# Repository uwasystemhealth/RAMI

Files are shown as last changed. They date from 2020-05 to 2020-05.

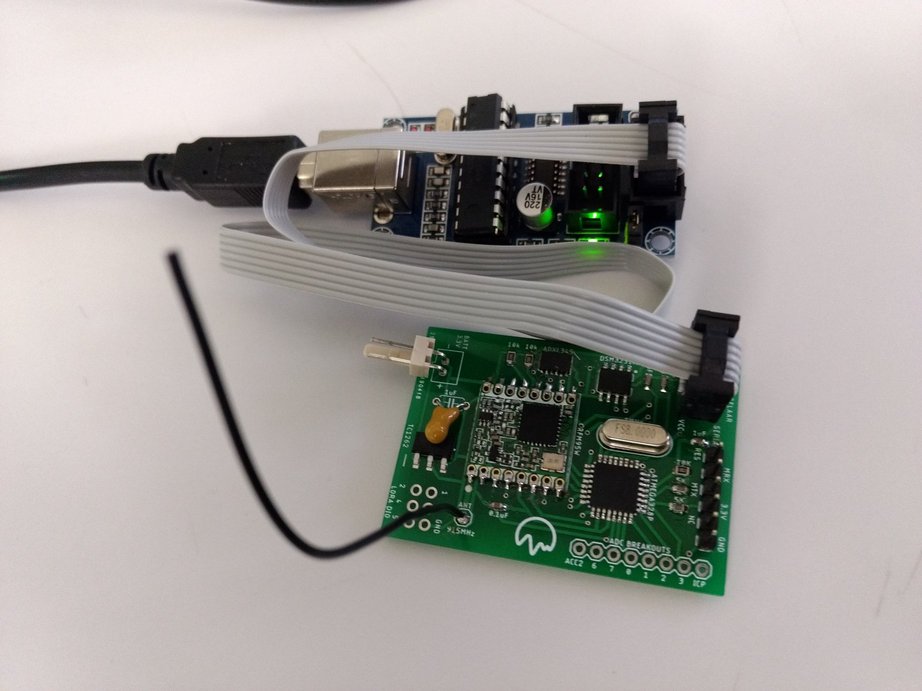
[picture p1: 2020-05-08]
figures/USBtinyISP.jpg

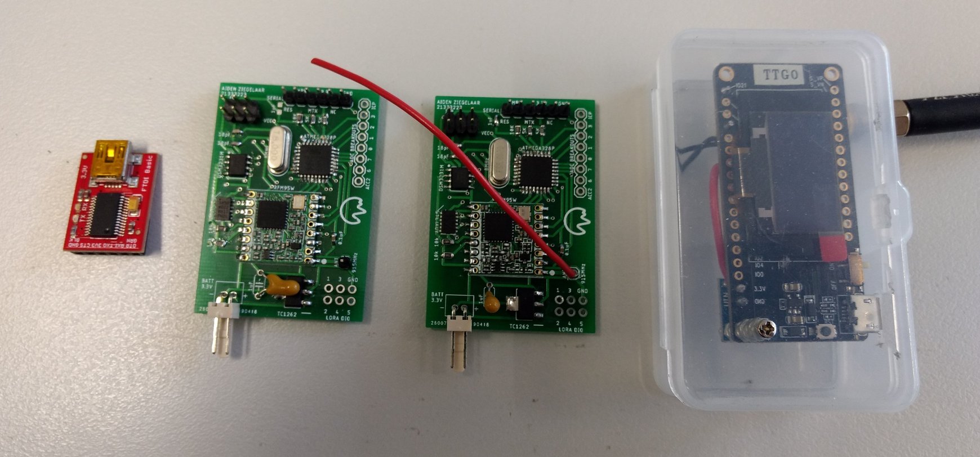
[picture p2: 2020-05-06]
figures/IMG_20200214_084231396.jpg

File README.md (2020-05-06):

# Remote Asset Management Indicator (RAMI)

This is a companion repository to the paper
_Sensing system for low cost condition monitoring of remote assets_
by Aiden J Ziegelaar, Ben C Travaglione & Melinda R Hodkiewicz,
published in
[4th IFAC Workshop on Advanced Maintenance Engineering, Services and Technologies](https://www.amest2020.eng.cam.ac.uk/).

This repository contains all the information necessary to replicate the results presented in the paper.

The majority of the notes are contained within the [Jupyter](https://jupyter.org/) notebook [RAMI.ipynb](RAMI.ipynb).

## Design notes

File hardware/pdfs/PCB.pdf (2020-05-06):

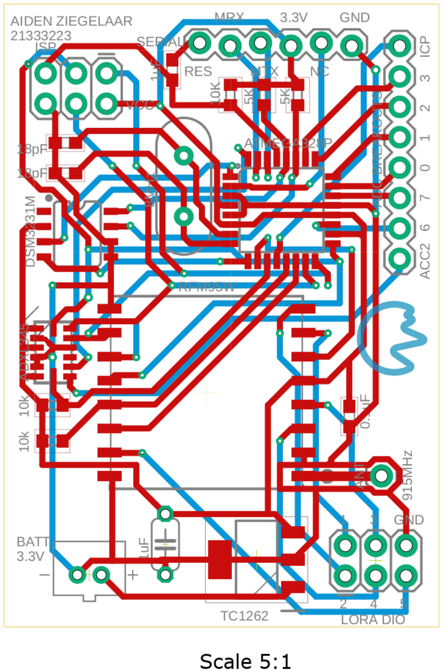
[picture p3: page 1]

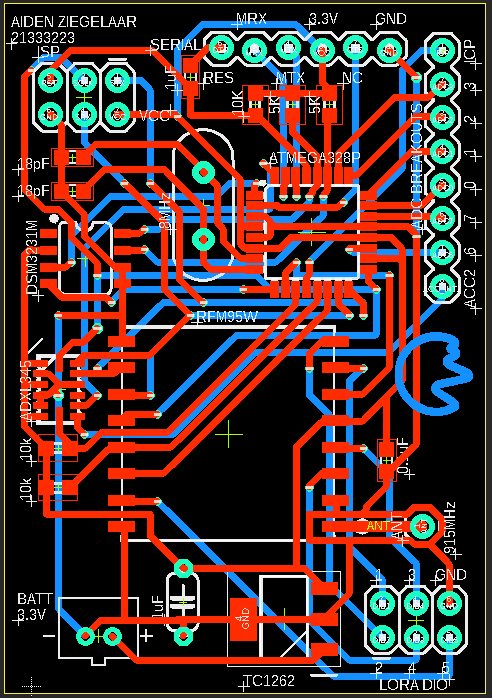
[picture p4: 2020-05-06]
figures/board_layout.png

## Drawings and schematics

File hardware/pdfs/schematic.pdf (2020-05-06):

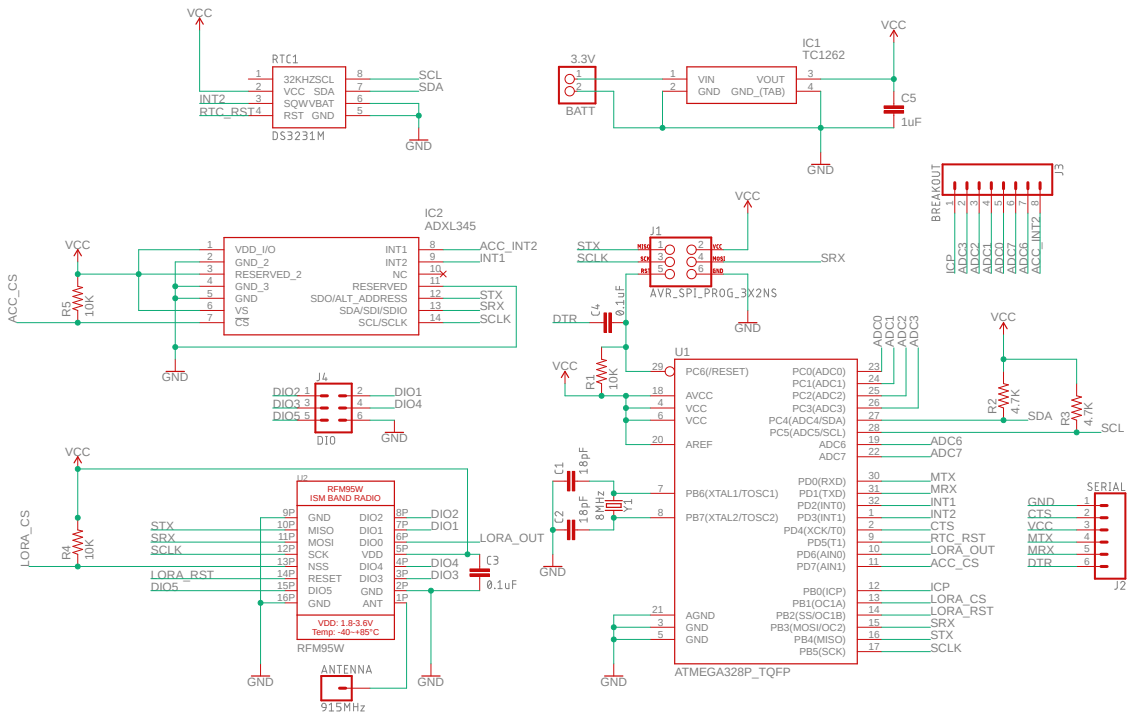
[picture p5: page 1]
ATMEGA328P_TQFP; ADXL345; VCC; GND; 1uF 10K ¹⁰K; PB5(SCK); PB7(XTAL2/TOSC2) 8; PB6(XTAL1/TOSC1) 7; GND 3 GND 5; VCC 4 VCC 6; AGND 21; AREF 20; AVCC 18; PB4(MISO); 16 PB3(MOSI/OC2); 13 PB0(ICP); PD7(AIN1); 11 PD6(AIN0); PD4(XCK/T0); PD3(INT1); PD2(INT0); 32 PD1(TXD); 31 PD0(RXD); ADC7; 22 ADC6; 19 PC5(ADC5/SCL); 28 PC4(ADC4/SDA); 27 PC3(ADC3); 26 PC2(ADC2); 25 PC1(ADC1); 24 PC0(ADC0); 23 PC6(/RESET) 29 U1; GND 5; GND_2 2; GND_3 4; INT1; INT2; RESERVED; 11 RESERVED_2 3; SCL/SCLK; 14 SDA/SDI/SDIO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

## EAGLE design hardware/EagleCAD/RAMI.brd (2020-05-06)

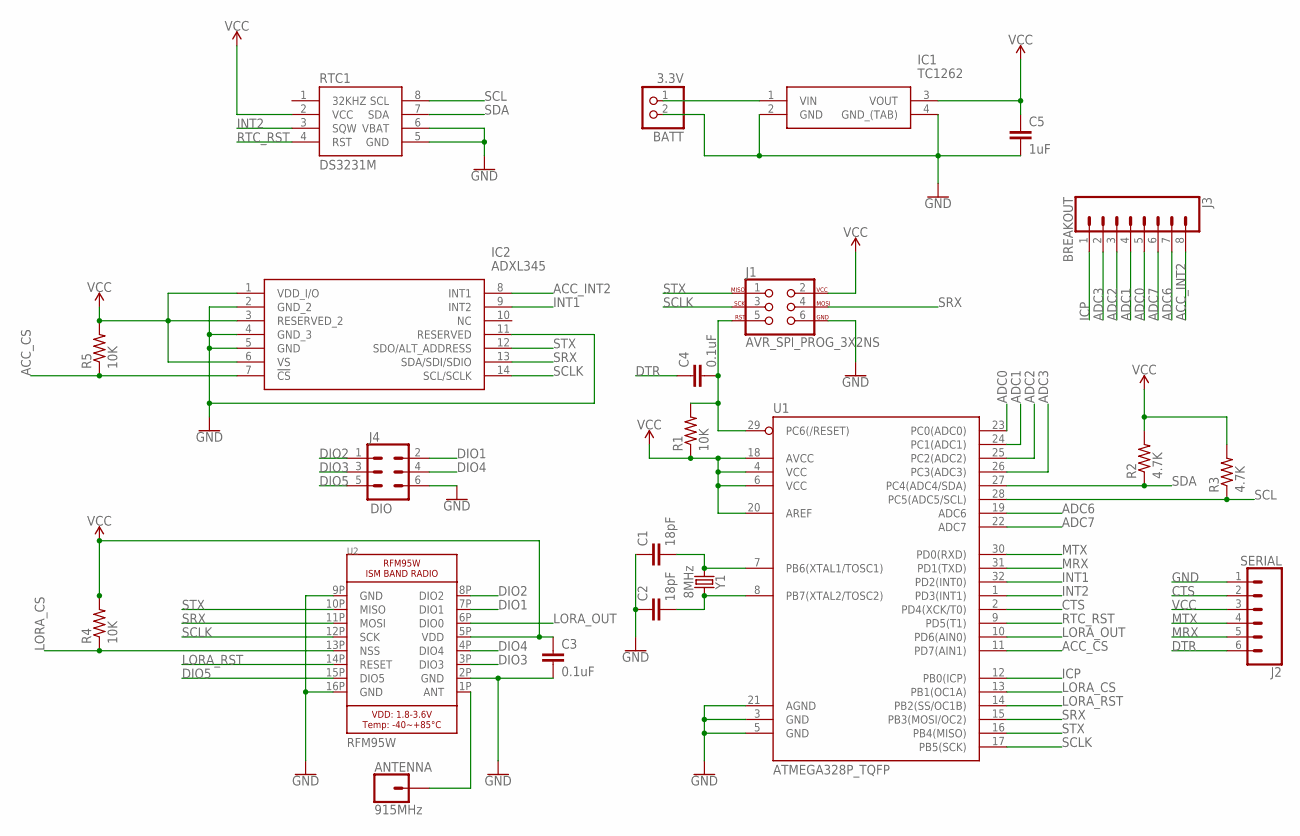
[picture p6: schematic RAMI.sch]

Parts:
ANTENNA: 915MHz; 1X01
BATT: 3.3V; JST-PH-2-THM
C1, C2: 18pF; 0603
C3, C4: 0.1uF; 0603
C5: 1uF; C050-024X044
IC1: TC1262; SOT230P700X180-4N
IC2: ADXL345; LGA14R80P3X6_300X500X100
J1: AVR_SPI_PROG_3X2NS; 2X3-NS
J2: SERIAL; 1X06_LOCK
J3: BREAKOUT; 1X08
J4: DIO; 2X3-NS
R1, R4, R5: 10K; R0603
R2, R3: 4.7K; R0603
RTC1: DS3231M; SO08
U1: ATMEGA328P_TQFP; TQFP32-08
U2: RFM95W; RFM95W_SMT
Y1: 8MHz; HC49US

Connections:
ACC_CS: IC2.7 (!CS), R5.1, U1.11 (PD7(AIN1))
ACC_INT2: IC2.8 (INT1), J3.8
ADC0: J3.5, U1.23 (PC0(ADC0))
ADC1: J3.4, U1.24 (PC1(ADC1))
ADC2: J3.3, U1.25 (PC2(ADC2))
ADC3: J3.2, U1.26 (PC3(ADC3))
ADC6: J3.7, U1.19 (ADC6)
ADC7: J3.6, U1.22 (ADC7)
ANT: ANTENNA.1, U2.1P (ANT)
CTS: J2.2, U1.2 (PD4(XCK/T0))
DIO1: J4.2, U2.7P (DIO1)
DIO2: J4.1, U2.8P (DIO2)
DIO3: J4.3, U2.3P (DIO3)
DIO4: J4.4, U2.4P (DIO4)
DIO5: J4.5, U2.15P (DIO5)
DTR: C4.1, J2.6
GND: BATT.2 (1), C1.1, C2.1, C3.2, C5.2, IC1.2 (GND), IC1.4 (GND_(TAB)), IC2.2 (GND_2), IC2.4 (GND_3), IC2.5 (GND), IC2.11 (RESERVED), J1.6, J2.1, J4.6, RTC1.5 (GND), RTC1.6 (VBAT), U1.3 (GND), U1.5 (GND), U1.21 (AGND), U2.2P (GND), U2.9P (GND), U2.16P (GND)
ICP: J3.1, U1.12 (PB0(ICP))
INT1: IC2.9 (INT2), U1.32 (PD2(INT0))
INT2: RTC1.3 (SQW), U1.1 (PD3(INT1))
LORA_CS: R4.1, U1.13 (PB1(OC1A)), U2.13P (NSS)
LORA_OUT: U1.10 (PD6(AIN0)), U2.6P (DIO0)
LORA_RST: U1.14 (PB2(SS/OC1B)), U2.14P (RESET)
MRX: J2.5, U1.31 (PD1(TXD))
MTX: J2.4, U1.30 (PD0(RXD))
unnamed: C1.2, U1.7 (PB6(XTAL1/TOSC1)), Y1.1
unnamed: C2.2, U1.8 (PB7(XTAL2/TOSC2)), Y1.2
unnamed: BATT.1 (2), IC1.1 (VIN)
RST: C4.2, J1.5, R1.2, U1.29 (PC6(/RESET))
RTC_RST: RTC1.4 (RST), U1.9 (PD5(T1))
SCL: R3.1, RTC1.8 (SCL), U1.28 (PC5(ADC5/SCL))
SCLK: IC2.14 (SCL/SCLK), J1.3, U1.17 (PB5(SCK)), U2.12P (SCK)
SDA: R2.1, RTC1.7 (SDA), U1.27 (PC4(ADC4/SDA))
SRX: IC2.13 (SDA/SDI/SDIO), J1.4, U1.15 (PB3(MOSI/OC2)), U2.11P (MOSI)
STX: IC2.12 (SDO/ALT_ADDRESS), J1.1, U1.16 (PB4(MISO)), U2.10P (MISO)
VCC: C3.1, C5.1, IC1.3 (VOUT), IC2.1 (VDD_I/O), IC2.3 (RESERVED_2), IC2.6 (VS), J1.2, J2.3, R1.1, R2.2, R3.2, R4.2, R5.2, RTC1.2 (VCC), U1.4 (VCC), U1.6 (VCC), U1.18 (AVCC), U1.20 (AREF), U2.5P (VDD)

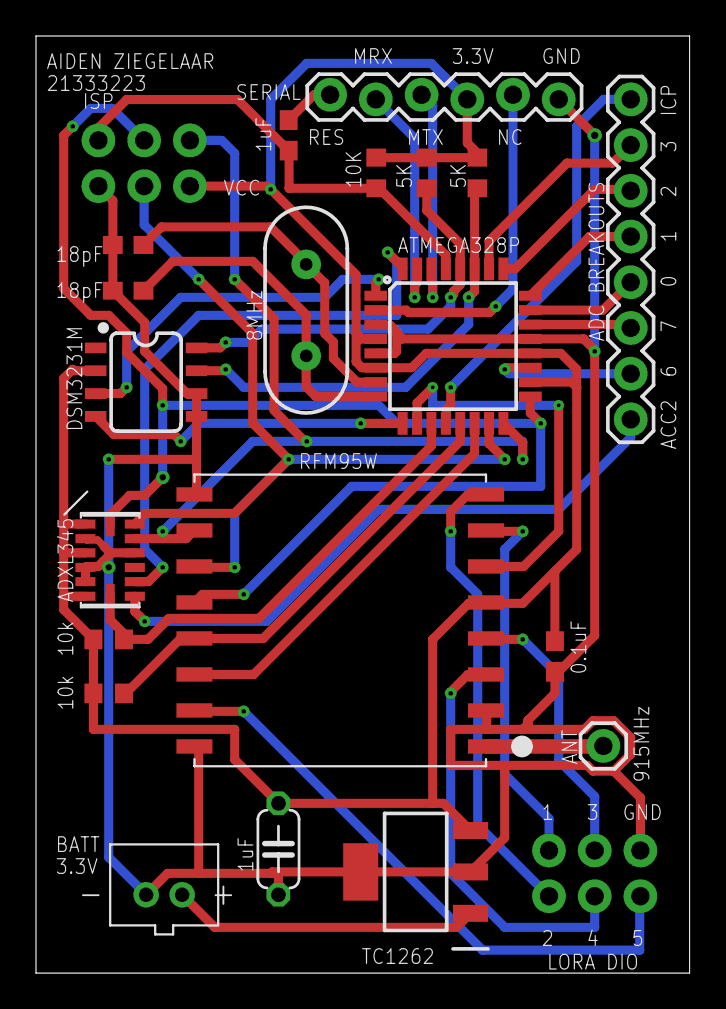
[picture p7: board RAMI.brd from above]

Board: 2 copper layers, 36.3 x 52.1 mm, 22 parts (0 on the bottom side), 36 nets.

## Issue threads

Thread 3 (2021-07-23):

RAMI Enclosure

Mechsmith, 2021-07-23:
Consists of:
- Decide on final design
- Draw design in Autodesk Inventor
- 3D print prototype
- Iterate to meet IP rating (>IP65 ideal)

Mechsmith, 2021-11-26:
The decision was made to go ahead and create the RAMI enclosure for the existing RAMI board. Once the RAMI v2 is complete, a separate enclosure can be made for that too.

Current enclosure has the body complete, but gasket channel still needs work. Lid and screw holes still need to be created.

Mechsmith, 2022-01-27:
Gasket channel is complete, but needs sizing to be matched to an off-the-shelf O-ring. Lid and screw holes still need to be completed (equivalent gasket channel needs to be sized on the lid too).

mhodki, 2022-06-03:
Update by Teams from Patrick today
Update on the RAMI is that I have found an o-ring supplier in Kwinana, but it is unclear exactly what sizes they have, so I'm going to need to drive down and have a look. I did an IP test using some DIY gasket, but faced a problem with the print de-laminating when I screwed the lid on. Next steps are to go to Kwinana to have a look and print out the new version of the enclosure with modified screw holes (drawing is already made).

Mechsmith, 2022-06-30:
Attempted to modify closure design to accommodate the O-ring, however printing it in ABS keeps failing so we need to order more PLA to complete the print (the O-ring groove should be the correct size in the updated CAD drawing).

mhodki, 2022-07-15:
@Mechsmith  - remind me again if you will be using RAMI for your thesis.

Mechsmith, 2022-07-21:
@mhodki Yes, if we can get some RAMIs operational they will be a good test case in my thesis.

mhodki, 2022-10-21:
Closing this project and now being worked on as part of Patrick's thesis

Closed 2022-10-21.

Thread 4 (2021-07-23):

LoRa IDs for Adrian

Mechsmith, 2021-07-23:
Consists of:
- Are LoRa IDs manually configurable?
- Produce a list of LoRa IDs for the PCBs we currently have
- Give the IDs to Adrian for the SimplyCity IoT network

Mechsmith, 2021-09-03:
Adrian has responded saying that he will look into setting up a trial with SimplyCity IoT.

Mechsmith, 2021-10-15:
[RE_ RAMI questions.pdf](https://github.com/uwasystemhealth/RAMI/files/7350542/RE_.RAMI.questions.pdf)

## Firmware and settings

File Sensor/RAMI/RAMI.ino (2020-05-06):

#include <avr/sleep.h>
#include <avr/power.h>
#include <Wire.h>
#include <SPI.h>
#include <SparkFun_ADXL345.h>
#include <RtcDS3231.h>
#include <EEPROM.h>
#include <LoRa.h>

//#define DEBUG // Comment out this line to turn off debug mode and save some power

#ifdef DEBUG
#define DEBUG_PRINT(msg) Serial.println(msg)
#else
#define DEBUG_PRINT(msg)
#endif

#define BAND            915E6  // Different RAMI devices have different bands
#define DEVICE_ID       0x01
#define TIMEOUT         200 //time to wait for a response from the server (x50ms)


// ADXL345 definitions
#define accIntPin             2
#define accCsPin              7
#define accRange              8 // valid values are 2g, 4g, 8g or 16g, (2, 4, 8, 16)
#define accThreshold          20 // The Scale Factor is 62.5mg/LSB, values are between 0 and 255.

//LoRa definitions
#define loraIntPin            6
#define loraRstPin            10
#define loraCsPin             9

//RTC Definitions
#define rtcIntPin             3
#define rtcRstPin             5
#define monitoringTime        5 // Time period to collect ADXL samples (seconds)
#define rtcActiveAlarmTime    120 // Time between wakes on active state (seconds)
                               // it is important that this time is greater than
                               // the monitoring time
#define rtcInactiveAlarmTime  240 // must be <86400 (one day) // Time between hearbeats (seconds)

// lets interrupts safely modify
volatile bool rtcInterruptFlag = false;
volatile bool accInterruptFlag = false;
volatile bool accInactiveInterruptFlag = false;
volatile bool stateFlag = false;

unsigned long nonce = 0;

unsigned int previous_magnitude = 0;

ADXL345 adxl;

RtcDS3231<TwoWire> Rtc(Wire);

void setup() {
  //////////////// Configure ATMEGA328P ////////////////
  SPI.begin();
  // turn off all non essential components
  power_adc_disable   ();
  #ifndef DEBUG
  power_timer1_disable();
  power_usart0_disable(); // This disables serial communications
  #else
  Serial.begin(9600);
  DEBUG_PRINT("DEBUG enabled");
  #endif

  ////////////////// Configure LoRa ////////////////
  LoRa.setPins(loraCsPin, loraRstPin, loraIntPin);
  LoRa.setSpreadingFactor(12);
  LoRa.setSignalBandwidth(31.25E3);
  LoRa.setCodingRate4(8);
  LoRa.setPreambleLength(8);
  LoRa.setSyncWord(0xfa);

  //////////////// Configure ADXL345 ////////////////
  adxl = ADXL345(accCsPin);
  adxl.powerOn();                     // Power on the ADXL345
  adxl.setRangeSetting(16);           // Give the range settings
                                      // Accepted values are 2g, 4g, 8g or 16g
                                      // Higher Values = Wider Measurement Range
                                      // Lower Values = Greater Sensitivity

  adxl.setSpiBit(0);                  // Configure the device to be in 4 wire SPI mode when set to '0' or 3 wire SPI mode when set to 1
                                      // Default: Set to 1
                                      // SPI pins on the ATMega328: 11, 12 and 13 as reference in SPI Library 
   
  adxl.setActivityXYZ(1, 1, 1);       // Set to activate movement detection in the axes "adxl.setActivityXYZ(X, Y, Z);" (1 == ON, 0 == OFF)
  adxl.setActivityThreshold(accThreshold);      // 62.5mg per increment   // Set activity   // Inactivity thresholds (0-255)
 
  adxl.setInactivityXYZ(1, 1, 1);     // Set to detect inactivity in all the axes "adxl.setInactivityXYZ(X, Y, Z);" (1 == ON, 0 == OFF)
  adxl.setInactivityThreshold(accThreshold);    // 62.5mg per increment   // Set inactivity // Inactivity thresholds (0-255)
  adxl.setTimeInactivity(60);         // How many seconds of no activity is inactive 0-255

  adxl.setTapDetectionOnXYZ(1, 1, 1); // Detect taps in the directions turned ON "adxl.setTapDetectionOnX(X, Y, Z);" (1 == ON, 0 == OFF)
 
  // Set values for what is considered a TAP and what is a DOUBLE TAP (0-255)
  adxl.setTapThreshold(50);           // 62.5 mg per increment
  adxl.setTapDuration(15);            // 625 μs per increment
  adxl.setDoubleTapLatency(80);       // 1.25 ms per increment
  adxl.setDoubleTapWindow(200);       // 1.25 ms per increment
 
  // Set values for what is considered FREE FALL (0-255)
  adxl.setFreeFallThreshold(7);       // (5 - 9) recommended - 62.5mg per increment
  adxl.setFreeFallDuration(30);       // (20 - 70) recommended - 5ms per increment
  
  // Turn on Interrupts for each mode (1 == ON, 0 == OFF)
  adxl.InactivityINT(0);
  adxl.ActivityINT(1);
  adxl.FreeFallINT(1);
  adxl.doubleTapINT(1);
  adxl.singleTapINT(1);

  // Make interrupts occur on pin 1
  adxl.setImportantInterruptMapping(2,2,2,2,2);
  adxl.setInterruptLevelBit(1); //Make the interrupt active low so we can use it to wake the ATMEGA328P
  
  // power minimisation for ADXL345
  adxl.setRate        (12.5);
  adxl.setLowPower    (1);
  
  //////////////// Configure DSM3231M ////////////////
  
  pinMode(rtcRstPin, OUTPUT);
  digitalWrite(rtcRstPin, HIGH);
  
  Rtc.Begin();
  
  RtcDateTime compiled = RtcDateTime(__DATE__, __TIME__);
  
  // Check if we have a vaild DateTime and if we can connect, if not print error or reset datetime to compiletime.
  if (!Rtc.IsDateTimeValid()) 
  {
      if (Rtc.LastError() != 0)
      {
          DEBUG_PRINT("RTC communications error = ");
          DEBUG_PRINT(Rtc.LastError());
      }
      else
      {
          DEBUG_PRINT("RTC lost confidence in the DateTime!");
          Rtc.SetDateTime(compiled);
      }
  }
  
  if (!Rtc.GetIsRunning()) {
    DEBUG_PRINT("RTC was not actively running, starting now");
    Rtc.SetIsRunning(true);
  }
  
  Rtc.Enable32kHzPin(false);
  Rtc.SetSquareWavePin(DS3231SquareWavePin_ModeAlarmOne);
  
  RtcDateTime now = Rtc.GetDateTime();
  if (now < compiled) 
  {
      DEBUG_PRINT("RTC is older than compile time!  (Updating DateTime)");
      Rtc.SetDateTime(compiled);
  }
  
  // set an alarm to trigger heartbeat
  // first signal sent ten seconds into future
  RtcDateTime alarmTime = now + 10;
  DS3231AlarmOne alarm1(
    alarmTime.Day(),
    alarmTime.Hour(),
    alarmTime.Minute(), 
    alarmTime.Second(),
    DS3231AlarmOneControl_HoursMinutesSecondsMatch);
  Rtc.SetAlarmOne(alarm1);
  Rtc.LatchAlarmsTriggeredFlags();

  if (!LoRa.begin(BAND)) {
    DEBUG_PRINT("Starting LoRa failed!");
    while (1);
  }

  // attachInterrupts 
  DS3231AlarmFlag flag = Rtc.LatchAlarmsTriggeredFlags();
  adxl.getInterruptSource();
  pinMode(accIntPin, INPUT_PULLUP);
  pinMode(rtcIntPin, INPUT_PULLUP);
  attachInterrupt(digitalPinToInterrupt(rtcIntPin), rtcInt, LOW);
  attachInterrupt(digitalPinToInterrupt(accIntPin), adxlInt, LOW);
}

void adxlInt() {
  sleep_disable();
  accInterruptFlag = true;  
  stateFlag = true;
  DEBUG_PRINT("ADXL int");
  detachInterrupt(digitalPinToInterrupt(accIntPin));
}

void adxlInactiveInt() {
  sleep_disable();
  accInactiveInterruptFlag = true;
  DEBUG_PRINT("ADXL inactive int");
  detachInterrupt(digitalPinToInterrupt(accIntPin));
}

void rtcInt () {
  sleep_disable();
  rtcInterruptFlag = true;
  detachInterrupt(digitalPinToInterrupt(rtcIntPin));
}

void inactiveRun(){
  DS3231AlarmFlag flag = Rtc.LatchAlarmsTriggeredFlags();
  byte adxl_int = adxl.getInterruptSource();
  if (flag & DS3231AlarmFlag_Alarm1) {
    //transmitStillAlive();
    DEBUG_PRINT("Device woken by RTC for Keepalive");
    RtcDateTime now = Rtc.GetDateTime();
    now = now + rtcInactiveAlarmTime;
    DS3231AlarmOne alarm1(
            now.Day(),
            now.Hour(),
            now.Minute(), 
            now.Second(),
            DS3231AlarmOneControl_HoursMinutesSecondsMatch); // longest time between heatbeats is 1 day in this configuration
                                                             // this can be extended to a maximum of one month if required
    Rtc.SetAlarmOne(alarm1);
    writeToLora(0x01, NULL);
  }
  if (accInterruptFlag) {
    stateFlag = true;
  }
  rtcInterruptFlag = false;
  accInterruptFlag = false;
  attachInterrupt(digitalPinToInterrupt(rtcIntPin), rtcInt, LOW);
  attachInterrupt(digitalPinToInterrupt(accIntPin), adxlInt, LOW);
  return;
}

void activeRun(){
  detachInterrupt(digitalPinToInterrupt(accIntPin));
  byte adxl_int = adxl.getInterruptSource();
  adxl.InactivityINT(1);
  adxl.ActivityINT(0);
  adxl.FreeFallINT(0);
  adxl.doubleTapINT(0);
  adxl.singleTapINT(0);
  detachInterrupt(digitalPinToInterrupt(rtcIntPin));
  DS3231AlarmFlag flag = Rtc.LatchAlarmsTriggeredFlags(); // Latch flags here incase inactivity & monitoriong time are equal
  if (accInactiveInterruptFlag) {
    accInactiveInterruptFlag = false;
    stateFlag = false;
    DEBUG_PRINT("Inactivity interrupt triggered. Setting state to inactive");
    RtcDateTime now = Rtc.GetDateTime();
    now = now + rtcInactiveAlarmTime;
    DS3231AlarmOne alarm1(
            now.Day(),
            now.Hour(),
            now.Minute(), 
            now.Second(),
            DS3231AlarmOneControl_HoursMinutesSecondsMatch); // longest time between heatbeats is 1 day in this configuration
                                                             // this can be extended to a maximum of one month if required
    Rtc.SetAlarmOne(alarm1);
    adxl.InactivityINT(0);
    adxl.ActivityINT(1);
    adxl.FreeFallINT(1);
    adxl.doubleTapINT(1);    
    adxl.singleTapINT(1);
    writeToLora(0x02, NULL);
    stateFlag = false;
    attachInterrupt(digitalPinToInterrupt(rtcIntPin), rtcInt, LOW);
    attachInterrupt(digitalPinToInterrupt(accIntPin), adxlInt, LOW);
    return;
  }
  attachInterrupt(digitalPinToInterrupt(accIntPin), adxlInactiveInt, LOW);
  unsigned int magnitude = 0;
  unsigned int maximum = 0;
  int x = 0;
  int y = 0;
  int z = 0;
  RtcDateTime now = Rtc.GetDateTime();
  now = now + rtcActiveAlarmTime + monitoringTime;
  DS3231AlarmOne alarm1(
          now.Day(),
          now.Hour(),
          now.Minute(), 
          now.Second(),
          DS3231AlarmOneControl_HoursMinutesSecondsMatch);
  Rtc.SetAlarmOne(alarm1);
  
  unsigned long elapsed = 0;
  unsigned long start = millis();
  while(elapsed < (monitoringTime*1000)){
    elapsed = millis() - start;
    adxl.readAccel(&x, &y, &z);
    magnitude = sqrt(x*x + y*y + z*z);
    if (magnitude > maximum){
      maximum = magnitude;
    }
  };
  DEBUG_PRINT(magnitude); 
  if (abs(magnitude - previous_magnitude) > accThreshold){
    previous_magnitude = magnitude;
    writeToLora(0x00, (byte*)(&previous_magnitude));
  }
  rtcInterruptFlag = false;
  accInterruptFlag = false;
  attachInterrupt(digitalPinToInterrupt(rtcIntPin), rtcInt, LOW);
  return;
}

void writeToLora(byte command, byte* dat){
  noInterrupts();
  LoRa.beginPacket();
  LoRa.write(command);
  LoRa.write(DEVICE_ID);
  LoRa.write(((byte*)&nonce)[0]);
  LoRa.write(((byte*)&nonce)[1]);
  if (dat != NULL) {
    LoRa.write(dat[1]);
    LoRa.write(dat[0]);
  }
  LoRa.endPacket();
  interrupts();
  nonce = nonce + 1;
  LoRa.sleep();
};

void loop() {
  #ifdef DEBUG
  Serial.print("RTC Interrupt Flag: ");
  DEBUG_PRINT(rtcInterruptFlag);
  Serial.print("ADXL Interrupt Flag: ");
  DEBUG_PRINT(accInterruptFlag);
  Serial.print("State Flag: ");
  DEBUG_PRINT(stateFlag);
  #else
  power_timer0_disable();
  set_sleep_mode (SLEEP_MODE_PWR_DOWN);
  sleep_cpu ();
  sleep_enable();
  power_timer0_enable();
  #endif
  if(stateFlag && (rtcInterruptFlag || accInterruptFlag)) {
    activeRun();
  } else if(rtcInterruptFlag || accInterruptFlag) {
    inactiveRun();
  } else {
    inactiveRun();
  }
  #ifdef DEBUG
  delay(1000);
  #endif
}

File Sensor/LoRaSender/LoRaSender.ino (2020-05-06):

//Libraries for LoRa
#include <SPI.h>
#include <LoRa.h>
#include <SparkFun_ADXL345.h>

//Libraries for OLED Display
#include <Wire.h>

//define SPI bus pins
#define SCK 13
#define MISO 12
#define MOSI 11

//define the pins used by the LoRa transceiver module
#define SS_LORA 9
#define RST 10
#define DIO0 6

//define the settings used by the ADXL345
#define SS_ADXL       7
#define INT_ADXL      2
#define RANGE_ADXL    8 // valid values are 2g, 4g, 8g or 16g, (2, 4, 8, 16)
#define ADXL_THRESH   10 // The Scale Factor is 62.5mg/LSB, values are between 0 and 255.

// Axis biases 
#define ADXL_X_BIAS   0
#define ADXL_Y_BIAS   0
#define ADXL_Z_BIAS   1

//433E6 for Asia
//866E6 for Europe
//915E6 for North America
#define BAND 915E6

//packet counter
int counter = 0;
int accIntPin       = 2;
int accCsPin        = 7;
int accRange        = 8; // valid values are 2g, 4g, 8g or 16g, (2, 4, 8, 16)
int accThreshold    = 10; // The Scale Factor is 62.5mg/LSB, values are between 0 and 255.

ADXL345 adxl;

void setup() {
  
  Serial.begin(9600);
  //SPI LoRa pins
  SPI.begin();
  //setup LoRa transceiver module
  LoRa.setPins(SS_LORA, RST, DIO0);
  LoRa.setSpreadingFactor(12);
  LoRa.setSignalBandwidth(31.25E3);
  LoRa.setCodingRate4(8);
  LoRa.setPreambleLength(8);
  LoRa.setSyncWord(0xfa);

  adxl = ADXL345(SS_ADXL);

  adxl.powerOn                ();
  adxl.setRangeSetting        (RANGE_ADXL);
  adxl.setSpiBit              (0); // 4-wire SPI
  adxl.setActivityXYZ         (1, 1, 1); // Use all axis
  adxl.setActivityThreshold   (ADXL_THRESH); // Threshold for interrupt
  
  if (!LoRa.begin(BAND)) {
    while (1);
  }
  delay(2000);
}

void loop() {
   
  Serial.print("Sending packet: ");
  Serial.println(counter);

  //Send LoRa packet to receiver
  LoRa.beginPacket();
  LoRa.print("hello ");
  LoRa.print(counter);
  LoRa.endPacket();

  counter++;
  
  delay(10000);
}

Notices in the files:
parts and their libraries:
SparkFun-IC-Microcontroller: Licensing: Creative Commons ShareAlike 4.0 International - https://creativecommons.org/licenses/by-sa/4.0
